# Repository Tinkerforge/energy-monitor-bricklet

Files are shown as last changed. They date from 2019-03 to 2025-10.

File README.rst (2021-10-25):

Energy Monitor Bricklet
=======================

This repository contains the firmware source code and the hardware design
files. The documentation generator configs can be found at
https://github.com/Tinkerforge/generators

Repository Content
------------------

software/:
 * examples/: Examples for all supported languages
 * build/: Compiled files
 * src/: Source code of firmware
 * Makefile: Makefile to build project

hardware/:
 * Contains KiCad project files and additionally schematics as PDF

datasheets/:
 * Contains datasheets for sensors and complex ICs that are used

Hardware
--------

The hardware is designed with the open source EDA Suite KiCad
(http://www.kicad.org). Before you are able to open the files,
you have to install the Tinkerforge kicad-libraries
(https://github.com/Tinkerforge/kicad-libraries). You can either clone
them directly in hardware/ or clone them in a separate folder and
symlink them into hardware/
(ln -s kicad_path/kicad-libraries project_path/hardware). After that you
can open the .pro file in hardware/ with KiCad and from there view and
modify the schematics and the PCB layout.

Software
--------

If you want to do your own Brick/Bricklet firmware development we highly
recommend that you use our build environment setup script and read the
tutorial (https://www.tinkerforge.com/en/doc/Tutorials/Tutorial_Build_Environment/Tutorial.html).

To compile the C code we recommend you to install the newest GNU Arm Embedded
Toolchain (https://launchpad.net/gcc-arm-embedded/+download).
You also need to install bricklib2 (https://github.com/Tinkerforge/bricklib2).

You can either clone it directly in software/src/ or clone it in a
separate folder and symlink it into software/src/
(ln -s bricklib_path/bricklib2 project_path/software/src/). Finally make sure to
have CMake installed (http://www.cmake.org/cmake/resources/software.html).

After that you can build the firmware by invoking make in software/.
The firmware (.zbin) can then be found in software/build/ and uploaded
with brickv (click button "Flashing" on start screen).

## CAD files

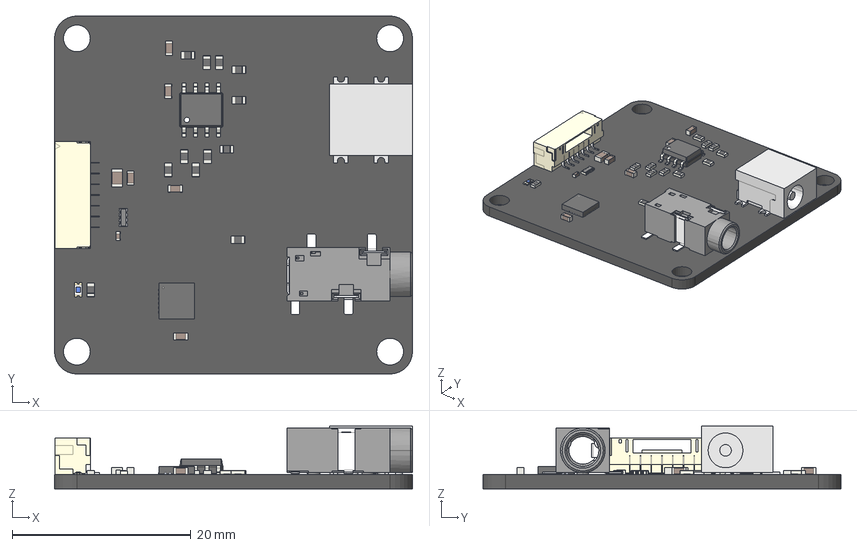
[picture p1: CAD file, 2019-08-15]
hardware/energy-monitor.step
40.0 x 40.0 x 7.00 mm
U7_CUI_SJ2-35813B-SMT-TR_5CB68745
U8_CUI_PJ-014DH-SMT-TR_5CC70F43
C1_C_0805_5C6327B4
C2_C_0603_5C6327BE
C3_C_0603_5C6327C8
C4_C_0603_5C6327D2
C5_C_0402_5C6327DC
C6_C_0603_5C6327E6
C7_C_0603_5C6327F0
D3_D_0603_blue_5C632801
P1_BrickletConn_7pin_5C632814
R1_R_0603_5C63282C
R2_R_0603_5C632836
R3_R_0603_5C632840
R4_R_0603_5C63284A
R5_R_0603_5C632854
R6_R_0603_5C63285E
R7_R_0603_5C632868
R8_R_0603_5C632872
R9_R_0603_5C63287C
R10_R_0603_5C632886
R11_R_0603_5C632890
R12_R_0603_5C63289A
RP1_Cut_5C636856
U1_QFN-24_4x4mm_Pitch0.5mm_5C6328CF
U2_soic_8_39x49_p127_5C6328E2

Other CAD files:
hardware/energy-monitor.FCStd

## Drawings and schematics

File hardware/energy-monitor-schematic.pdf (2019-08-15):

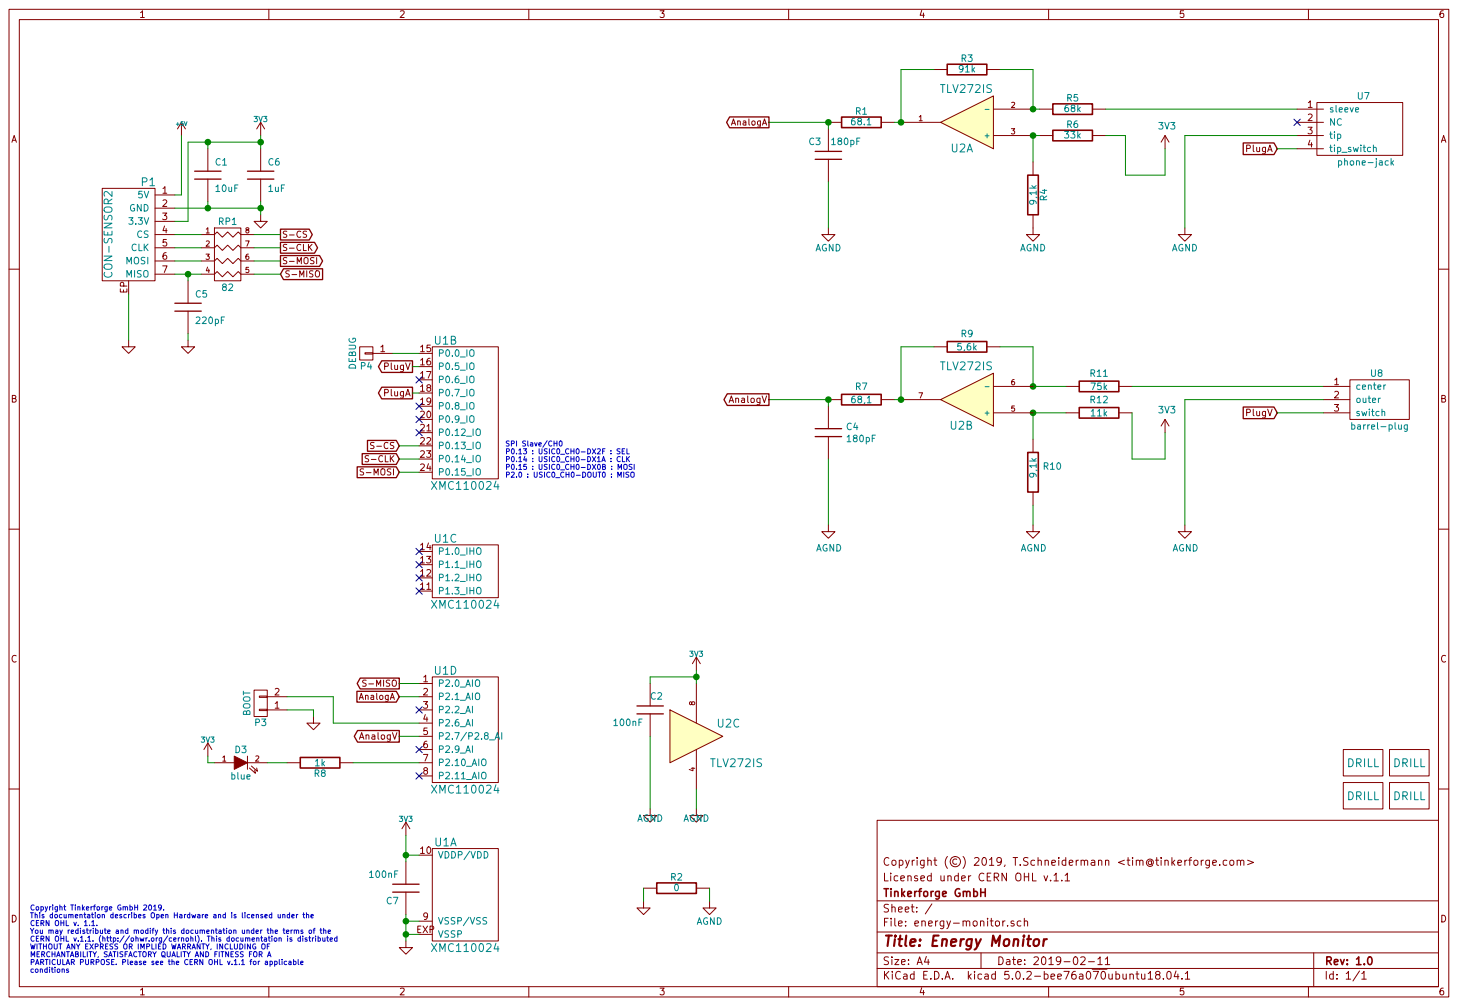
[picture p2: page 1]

Licensed under CERN OHL v.1.1 Copyright (©) 2019, T.Schneidermann <tim@tinkerforge.com>

File: energy-monitor.sch Sheet: / Tinkerforge GmbH

Copyright Tinkerforge GmbH 2019. This documentation describes Open Hardware and is licensed under the CERN OHL v. 1.1. You may redistribute and modify this documentation under the terms of the CERN OHL v.1.1. (http://ohwr.org/cernohl). This documentation is distributed WITHOUT ANY EXPRESS OR IMPLIED WARRANTY, INCLUDING OF MERCHANTABILITY, SATISFACTORY QUALITY AND FITNESS FOR A

Id: 1/1 Title: Energy Monitor

PARTICULAR PURPOSE. Please see the CERN OHL v.1.1 for applicable

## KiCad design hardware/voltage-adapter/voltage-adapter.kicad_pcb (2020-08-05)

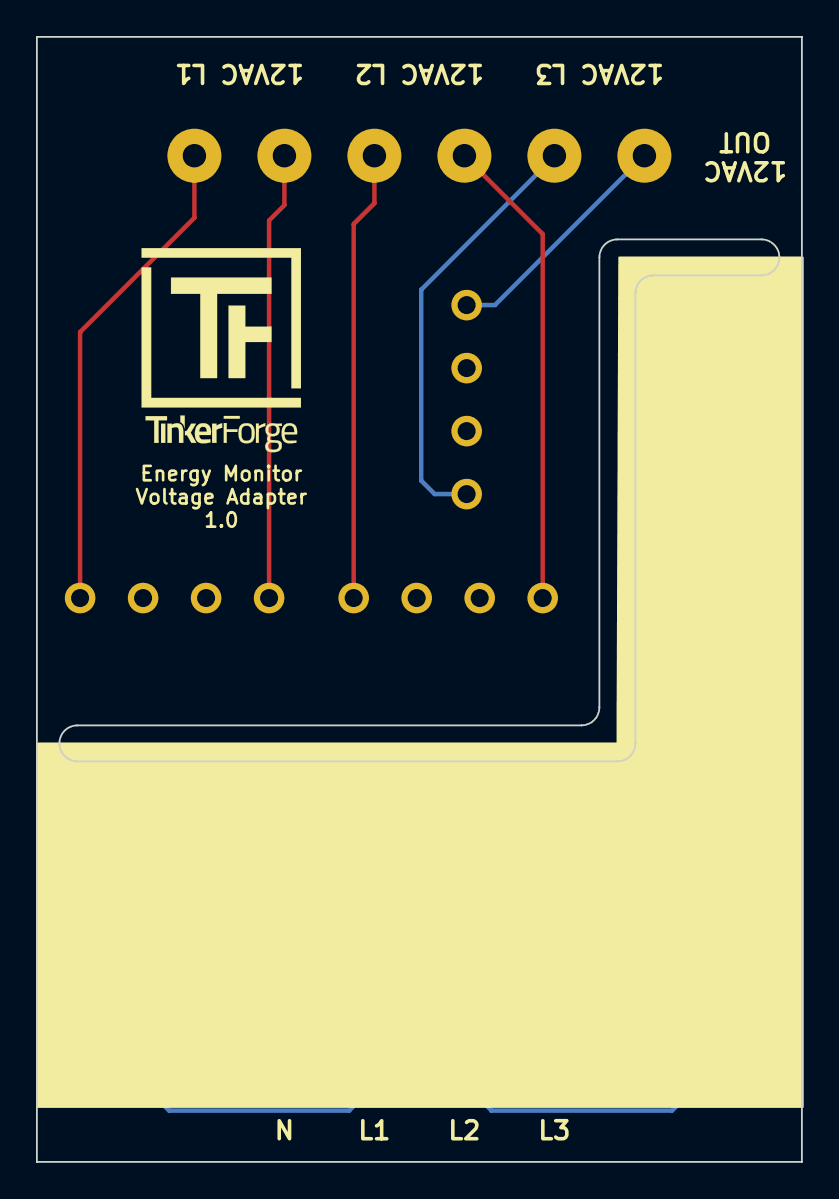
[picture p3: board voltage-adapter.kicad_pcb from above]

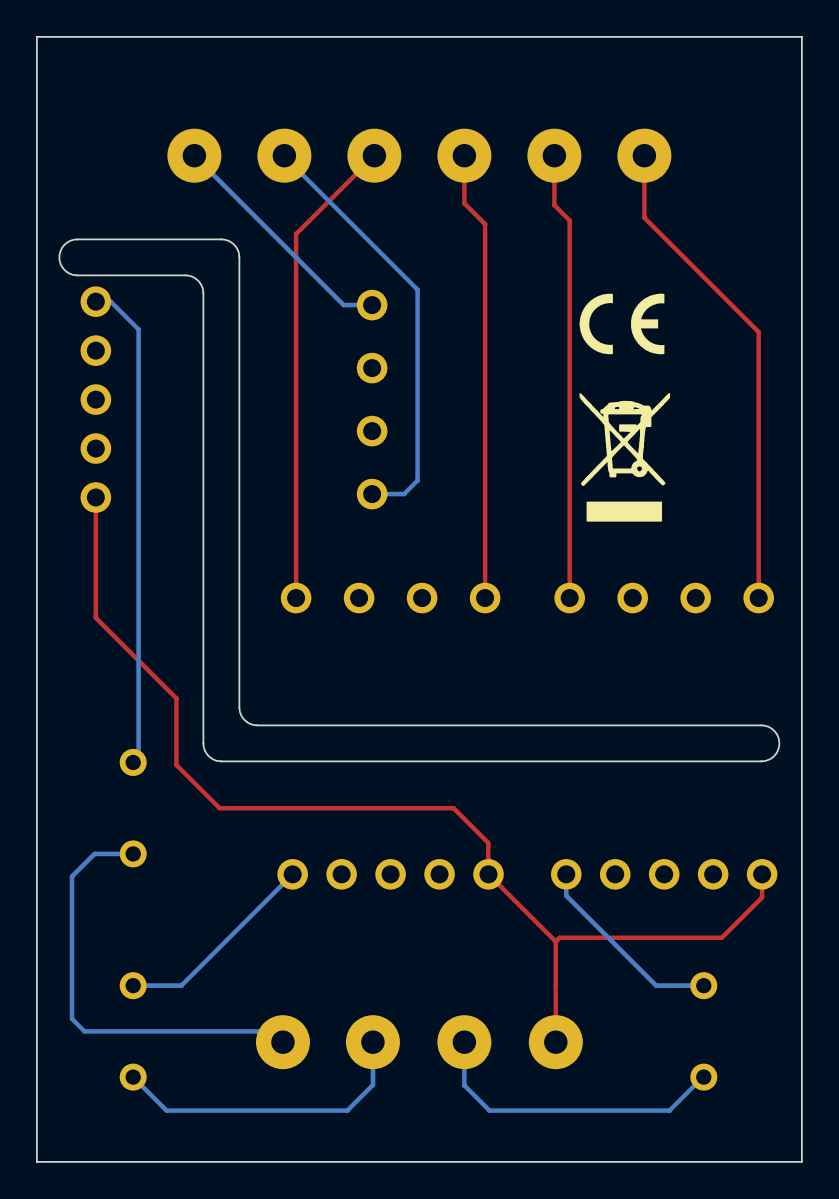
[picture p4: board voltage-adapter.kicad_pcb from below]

Board: 2 copper layers, 42.5 x 62.5 mm, 11 parts (2 on the bottom side), 13 nets.

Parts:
F1, F2, F3: MRF 50mA T; Fuse-MRF
P1: CONN_01X04; AKL_5_4
P3, P4: CONN_01X06; AKL_5_3
U1, U2, U3: Trafo-749118115; 749118115
VAL: WEEE_7mm
VAL#2: CE_5mm

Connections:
unnamed: F1.1, P1.2
unnamed: F1.2, U1.5
unnamed: F2.1, P1.3
unnamed: F2.2, U2.5
unnamed: F3.1, P1.4
unnamed: F3.2, U3.5
unnamed: P1.1, U1.1, U2.1, U3.1
unnamed: P3.1, U1.9
unnamed: P3.2, U1.6
unnamed: P3.3, U2.9
unnamed: P4.1, U2.6
unnamed: P4.2, U3.9
unnamed: P4.3, U3.6

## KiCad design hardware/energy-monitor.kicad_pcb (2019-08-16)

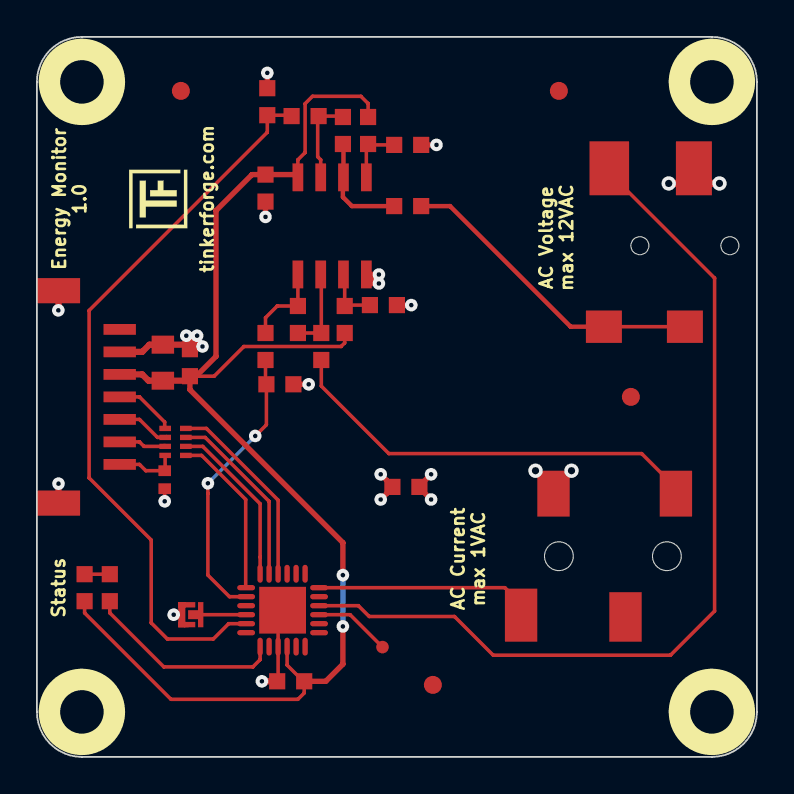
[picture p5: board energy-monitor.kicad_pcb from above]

Board: 2 copper layers, 40.0 x 40.0 mm, 38 parts (2 on the bottom side), 27 nets.

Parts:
C1: 10uF; C0805
C2, C7: 100nF; C0603F
C3, C4: 180pF; C0603F
C5: 220pF; C0402F
C6: 1uF; C0603F
D3: blue; D0603F
Fiducial_Mark: VAL**; Fiducial_Mark
Fiducial_Mark#2, Fiducial_Mark#3, Fiducial_Mark#4: VAL**; Fiducial_Mark
P1: CON-SENSOR2
P3: BOOT; SolderJumper
P4: DEBUG; DEBUG_PAD
R1: 68.1; R0603F
R2: 0; R0603F
R3: 91k; R0603F
R4, R10: 9,1k; R0603F
R5: 68k; R0603F
R6: 33k; R0603F
R7: 68,1; R0603F
R8: 1k; R0603F
R9: 5,6k; R0603F
R11: 75k; R0603F
R12: 11k; R0603F
RP1: 82; 4X0402
U1: XMC1300; QFN24-4x4mm-0.5mm
U2: TLV272IS; SOIC8
U3, U4, U5, U6: DRILL; DRILL_NP
U7: phone-jack; PJ-327C-3
U8: barrel-plug; DC-033
VAL: WEEE_7mm
VAL#2: CE_5mm

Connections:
3V3: C1.1, C2.2, C6.1, C7.2, D3.1, P1.3, R6.2, R12.1, U1.10, U2.8
AGND: C2.1, C3.1, C4.2, R2.2, R4.2, R10.2, U2.4, U7.3, U8.2
AnalogA: C3.2, R1.1, U1.2
AnalogV: C4.1, R7.2, U1.5
GND: C1.2, C5.2, C6.2, C7.1, P1.2, P1.EP, P3.1, R2.1, U1.9, U1.EXP
unnamed: C5.1, P1.7, RP1.4
unnamed: D3.2, R8.2
unnamed: P1.4, RP1.1
unnamed: P1.5, RP1.2
unnamed: P1.6, RP1.3
unnamed: P3.2, U1.4
unnamed: P4.1, U1.15
unnamed: R1.2, R3.1, U2.1
unnamed: R3.2, R5.1, U2.2
unnamed: R4.1, R6.1, U2.3
unnamed: R5.2, U7.1
unnamed: R7.1, R9.2, U2.7
unnamed: R8.1, U1.7
unnamed: R10.1, R12.2, U2.5
unnamed: R11.1, U8.1
unnamed: R9.1, R11.2, U2.6
PlugA: U1.18, U7.4
PlugV: U1.16, U8.3
S-CLK: RP1.7, U1.23
S-CS: RP1.8, U1.22
S-MISO: RP1.5, U1.1
S-MOSI: RP1.6, U1.24

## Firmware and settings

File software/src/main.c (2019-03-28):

/* energy-monitor-bricklet
 * Copyright (C) 2019 Olaf Lüke <olaf@tinkerforge.com>
 *
 * main.c: Initialization for Energy Monitor Bricklet
 *
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
 * You should have received a copy of the GNU Lesser General Public
 * License along with this library; if not, write to the
 * Free Software Foundation, Inc., 59 Temple Place - Suite 330,
 * Boston, MA 02111-1307, USA.
 */

#include <stdio.h>
#include <stdbool.h>

#include "configs/config.h"

#include "bricklib2/bootloader/bootloader.h"
#include "bricklib2/hal/system_timer/system_timer.h"
#include "bricklib2/logging/logging.h"
#include "communication.h"

#include "energy.h"

int main(void) {
	logging_init();
	logd("Start Energy Monitor Bricklet\n\r");

	communication_init();
	energy_init();

	while(true) {
		bootloader_tick();
		communication_tick();
		energy_tick();
	}
}

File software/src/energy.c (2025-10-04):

/* energy-monitor-bricklet
 * Copyright (C) 2019 Olaf Lüke <olaf@tinkerforge.com>
 *
 * energy.c: ADC read-out and voltage/ampere/energy calculation
 *
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
 * You should have received a copy of the GNU Lesser General Public
 * License along with this library; if not, write to the
 * Free Software Foundation, Inc., 59 Temple Place - Suite 330,
 * Boston, MA 02111-1307, USA.
 */

// On some systems, math.h declares a function named logf(float) to calculate
// the natural logarithm of a float number. bricklib2's logging.h defines
// a macro called logf(...) to log fatal errors. The hack below renames the
// unused logf from math.h to logf_math to avoid colliding with logf from
// logging.h.
#define logf logf_math
#include <math.h>
#undef logf


#include "energy.h"

#include "configs/config_energy.h"
#include "bricklib2/hal/system_timer/system_timer.h"
#include "bricklib2/bootloader/bootloader.h"
#include "bricklib2/logging/logging.h"
#include "bricklib2/utility/util_definitions.h"

#include "xmc_vadc.h"
#include "xmc_scu.h"
#include "xmc_wdt.h"
#include "xmc_math.h"

#define ENERGY_RATIO_CURRENT_DEFAULT 3000
#define ENERGY_RATIO_VOLTAGE_DEFAULT 1923

#define ENERGY_CROSSINGS_PER_CALCULATON 10
#define ENERGY_NO_WAVEFORM_THRESHOLD    3000

#define energy_adc_irq_handler IRQ_Hdlr_15

Energy energy;


uint32_t *const energy_samples_start = energy.samples;
uint32_t *const energy_samples_end   = energy.samples + ENERGY_SAMPLES_NUM - 1;
uint32_t *energy_samples_start_cur   = energy.samples;
uint32_t *energy_samples_end_cur     = energy.samples;

// 1 sample per 71.85us
// Interrupt takes 0.874us (measured with logic analyzer)
void __attribute__((optimize("-O3"))) __attribute__ ((section (".ram_code"))) energy_adc_irq_handler(void) {
	const uint16_t v = XMC_VADC_GROUP_GetDetailedResult(ENERGY_V_ADC_GROUP, ENERGY_V_ADC_RESULT_REG);
	const uint16_t a = XMC_VADC_GROUP_GetDetailedResult(ENERGY_A_ADC_GROUP, ENERGY_A_ADC_RESULT_REG);

	if(energy_samples_end_cur == energy_samples_end) {
		energy_samples_end_cur = energy_samples_start;
	} else {
		energy_samples_end_cur++;
	}
	*energy_samples_end_cur = ((uint32_t)a) | (((uint32_t)v) << 16);
}

void energy_write_offset_calibration(uint16_t a, uint16_t v) {
	uint32_t page[EEPROM_PAGE_SIZE/sizeof(uint32_t)];
	page[ENERGY_CALIBRATION_MAGIC_POS]    = ENERGY_CALIBRATION_MAGIC;
	page[ENERGY_OFFSET_CALIBRATION_A_POS] = a;
	page[ENERGY_OFFSET_CALIBRATION_V_POS] = v;

	if(!bootloader_write_eeprom_page(ENERGY_OFFSET_CALIBRATION_PAGE, page)) {
		// TODO: Error handling?
	}

	logd("Write offset calibration values: a %d, v %d\n\r", a, v);
}


void energy_read_offset_calibration(void) {
	uint32_t page[EEPROM_PAGE_SIZE/sizeof(uint32_t)];

	bootloader_read_eeprom_page(ENERGY_OFFSET_CALIBRATION_PAGE, page);

	// The magic number is not where it is supposed to be.
	// This is either our first startup or something went wrong.
	// We initialize the calibration data with sane default values.
	if(page[ENERGY_CALIBRATION_MAGIC_POS] != ENERGY_CALIBRATION_MAGIC) {
		energy.offset_current = 8167;
		energy.offset_voltage = 7962;

		energy_write_offset_calibration(energy.offset_current, energy.offset_voltage);

		return;
	}

	energy.offset_current = page[ENERGY_OFFSET_CALIBRATION_A_POS];
	energy.offset_voltage = page[ENERGY_OFFSET_CALIBRATION_V_POS];

	logd("Read offset calibration values: a %d, v %d\n\r", energy.offset_current, energy.offset_voltage);
}

void energy_calibrate_offset(void) {
	uint32_t a_sum = 0;
	uint32_t v_sum = 0;

	for(uint16_t i = 0; i < ENERGY_SAMPLES_NUM; i++) {
		const uint32_t sample = energy.samples[i];
		const uint16_t a = (sample >>  0) & 0xFFFF;
		const uint16_t v = (sample >> 16) & 0xFFFF;

		a_sum += a;
		v_sum += v;
	}

	energy.offset_current = a_sum / ENERGY_SAMPLES_NUM;
	energy.offset_voltage = v_sum / ENERGY_SAMPLES_NUM;

	energy_write_offset_calibration(energy.offset_current, energy.offset_voltage);
}


void energy_write_ratio_calibration(uint16_t a, uint16_t v) {
	uint32_t page[EEPROM_PAGE_SIZE/sizeof(uint32_t)];
	page[ENERGY_CALIBRATION_MAGIC_POS]    = ENERGY_CALIBRATION_MAGIC;
	page[ENERGY_RATIO_CALIBRATION_A_POS] = a;
	page[ENERGY_RATIO_CALIBRATION_V_POS] = v;

	if(!bootloader_write_eeprom_page(ENERGY_RATIO_CALIBRATION_PAGE, page)) {
		// TODO: Error handling?
	}

	logd("Write ratio calibration values: a %d, v %d\n\r", a, v);
}


void energy_read_ratio_calibration(void) {
	uint32_t page[EEPROM_PAGE_SIZE/sizeof(uint32_t)];

	bootloader_read_eeprom_page(ENERGY_RATIO_CALIBRATION_PAGE, page);

	// The magic number is not where it is supposed to be.
	// This is either our first startup or something went wrong.
	// We initialize the calibration data with sane default values.
	if(page[ENERGY_CALIBRATION_MAGIC_POS] != ENERGY_CALIBRATION_MAGIC) {
		energy.ratio_current = ENERGY_RATIO_CURRENT_DEFAULT;
		energy.ratio_voltage = ENERGY_RATIO_VOLTAGE_DEFAULT;

		energy_write_ratio_calibration(energy.ratio_current, energy.ratio_voltage);

		return;
	}

	energy.ratio_current = page[ENERGY_RATIO_CALIBRATION_A_POS];
	energy.ratio_voltage = page[ENERGY_RATIO_CALIBRATION_V_POS];

	logd("Read ratio calibration values: a %d, v %d\n\r", energy.ratio_current, energy.ratio_voltage);
}
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

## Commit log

2019-02-12 New repository. Added readme, gitignore, datasheet, schematic
    [energy-monitor.sch]
2019-02-12 added pcb design
    [energy-monitor.kicad_pcb, energy-monitor.sch]
2019-02-12 fix sym lib table, change pcb texts
    [energy-monitor.kicad_pcb]
2019-02-12 changed text layout, added fiducialmarks, ready for prototype
    [energy-monitor.kicad_pcb]
2019-03-07 changed resistor value for voltage measurement
    [energy-monitor.kicad_pcb, energy-monitor.sch]
2019-03-07 changed resistor values
    [energy-monitor.kicad_pcb, energy-monitor.sch]
2019-03-20 Add auto-generated firmware stub
    [cmake_config_custom.txt]
2019-03-28 Add implementation of main API
    [cmake_config_custom.txt]
2019-03-28 Add transformer calibration and status support
2019-04-29 changed resistor values, bigger footprint for dc-033, changed labeling
    [energy-monitor.kicad_pcb, energy-monitor.sch]
2019-04-29 Fix V ADC pin
    [config_energy.h]
2019-04-29 changed AnalogV pin from 2.2 to 2.7/2.8
    [energy-monitor.kicad_pcb, energy-monitor.sch]
2019-04-30 Update voltage/current ratio (values from actual transformer)
2019-05-09 fix footprint
    [energy-monitor.kicad_pcb]
2019-06-13 fix connector properties
    [energy-monitor.kicad_pcb]
2019-08-15 add 3d data
    [energy-monitor.FCStd, energy-monitor.kicad_pcb, energy-monitor.step]
2019-08-15 add schematic
    [energy-monitor.sch]
2019-08-16 changed processor to XMC1300
    [energy-monitor.kicad_pcb, energy-monitor.sch]
2019-08-22 c: Adapt to bindings changes
    [example_callback.c]
2019-08-23 Examples: Fix spelling of frequency.
    [example_callback.c, example_simple.c]
2019-09-09 Show voltage and current of 0 if the waveform has no zero-crossings
2020-08-05 added voltage adapter
    [voltage-adapter.kicad_pcb, voltage-adapter.sch]
2020-09-02 uc: Add example driver note.
2020-10-16 uc: Fix divisor type.
    [example_callback.c]
2020-10-26 examples: Fix typos in comments
    [example_callback.c, example_simple.c]
2021-10-25 Update KiCad link
    https://www.kicad.org/blog/2021/10/Avoid-links-to-former-kicad-domain/
2022-04-27 uc: Adapt to bindings changes
    [example_callback.c, example_simple.c]
2025-10-04 Fix compatibility with new Docker build image (GCC 14.2.1)
    [energy.c]

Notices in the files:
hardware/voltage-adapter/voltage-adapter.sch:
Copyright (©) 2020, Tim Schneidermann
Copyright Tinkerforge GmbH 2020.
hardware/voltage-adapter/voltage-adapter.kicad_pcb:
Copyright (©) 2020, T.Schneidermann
